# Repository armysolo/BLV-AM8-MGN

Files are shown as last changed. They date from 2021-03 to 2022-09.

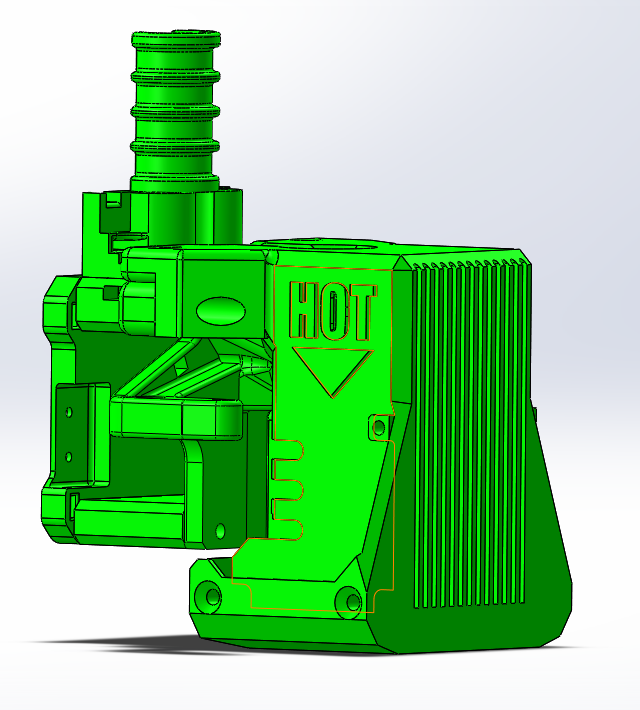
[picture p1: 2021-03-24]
BLV Cube X Carriage for AM8/Pictures/X Carriage Assembly.PNG

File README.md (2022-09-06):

# BLV-AM8-MGN  
# Notice for stepper wiring #  

* Don't trust the data sheet or other schematics to be correct. You should test the wires yourself to find the coil pairs. Do not connect/disconnect the stepper motors while the board has power. You can blow stepper drivers. With the motor wires NOT connected to anything:  
The idea is to find the two cables that form one of the two coils inside the stepper. If you short two wires together and the stepper shaft is hard to turn by hand you found one pair of wires for a coil.  
Example- If black and green wires are a pair call them coil 1, than red and blue can be coil 2.  
* Duet labels the Duet 2 Wifi stepper ports with 2B 2A(red-blue) and 1A 1B(green-black).  
* Duet 3 is labeled B1 B2(black-green) and A1 A2(red-blue).
 
# Rail Relocation Mod #  

* This mod is designed to move the linear rails from the front of the 2040 extrusions to the outside. Having the linear rails on the side makes installing the X 2020 considerably easier. Make sure you line up the linear rails with the 2020 jig from the original download.  

* The original X 2020 was 420mm. This modification will require a 450mm 2020 for the X. You can go longer but the new 2020 needs to be at least 30mm longer. There's 7 parts you'll need to print. View the pictures, the replacement parts are in green. You should be able to reuse the original parts. You'll also need a longer belt.  

# AM8 MGN CoreXY X Carriage #  
* I've modified the X carriage from the CoreXY to work with the AM8 MGN mod. You'll need to print the 7 parts from my mod that moves the linear rails to the outsides of 2040 and all 9 parts for the X carriage. This mod also moves the X endstop from the top of the 2020 to be recessed on the inside of the X Carriage Rear plate. It might not be necessary so you make the choice.  
 
# AM8 MGN CoreXY X Carriage #  
My modified Y belt setup. I didn't start with an original Anet instead I built everything custom from the ground up.  

## BOM ##  
* 2040 Y Motor  
** 2x M5x8mm button head screws  
** 2x M5 T-Nuts  
** 4x M3x8mm socket head screws  

* Y Adjustable Belt Holder  
** 4x M4x12 socket head screws  
** 4x M4 nuts  
** 3x M3 nuts  
** 1x M3x35mm socket head screw  
** 2x M3x6mm button head screws

* Y Tensioner  
** 4x M5x8mm button head screws  
** 4x M5 T-Nuts  
** 1x M3x20mm socket head screw  
** 3x M3 washers
** 2x F6232ZZ bearings

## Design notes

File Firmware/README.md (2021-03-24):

## Firmware
I will only update my configuration files for the latest released versions. I won't do it for the beta versions because they change too frequent. If you find any issues PM me on Facebook. I'm trying to highlight any useful or important information so if I missed something I apologize.  

This firmware will work without modifications needed ONLY if you follow my wiring diagrams. Study and understand the wiring diagrams before you start plugging things in.  

Make sure your M208 in config.g is configured correctly for max and min.  

If upgrading from Duet RRF2 you need to update to RRF3.0.0 before going to the latest released version. After updating to RRF3.0.0 you can go to RRF3.#.#.  

https://duet3d.dozuki.com/Wiki/Installing_and_Updating_Firmware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  

There are a number of changes in RRF3 which makes some of the RRF2 Gcode incompatible.  

https://duet3d.dozuki.com/Wiki/RepRapFirmware_3_overview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  

Become familiar with the firmware. Learn to troubleshoot and use the Duet resources. You'll learn more if figure it out on your own vs always asking someone to fix it for you. Make sure you're using the latest version of the firmware.  

After your build is assembled and firmware configured, DO THE COMMISSION TESTING!!!! I can't stress that enough. It can prevent damage to the printer or the main board.  

https://duet3d.dozuki.com/Wiki/Step_by_step_guide#Section_Commissioning_tests  

Duet Resources/Useful links  
https://duet3d.dozuki.com/Wiki/Getting_Started_With_Duet_3  
https://duet3d.dozuki.com/Wiki/Step_by_step_guide  
https://duet3d.dozuki.com/Wiki/Gcode  
https://duet3d.dozuki.com/Wiki/Bed_levelling_using_multiple_independent_Z_motors  
https://duet3d.dozuki.com/  
https://forum.duet3d.com/  
https://www.blvprojects.com/  

# Independent leveling:  
You must use M671 to define the X and Y coordinates of the leadscrews.  
M671 must come after the M584, M667 or M669.  
Must specify the same quantity of X and Y coordinates as the number of motors assigned to the Z axis in M584  
These coordinates must be in the same order as the driver numbers of the associated motors in M584. 
Define it with the physical location in relation to the nozzle. The S parameter is for the max allowed adjustment.  
G30 defines where the head will probe to calculate the offset.  

**2 Z motors**  
One at each end of the X axis  
Set the Y coordinates of the leadscrews in M671 to be equal (the value doesn't matter, so you can use zero).  
Use at least two probe points, one at each end of the X axis.  
All your probe points should have the same Y coordinate, which should be at or near the middle of the printable range.  

Define the driver in config.g `M584 Z0.3:0.4`  
`M671 X-48.5:360 Y150:150 S10`  
The order the coordinates appear are important. The stepper located at -48.5,150 must be connected to driver 3  
The stepper located at 360,150 must be connected to driver 4  

In bed.g  
`G30 P0 X55 Y161 Z-99999 ; Probe near left lead screw position`  
`G30 P1 X328 Y161 Z-99999 S2 ; Probe near right lead screw position`  

-Note: If you are experiencing the Z axis compensating in the opposite direction needed, that means your Z motors are swapped. 
You can either swap the X values in the M671 command, or swap the stepper motors plugged into the Duet.

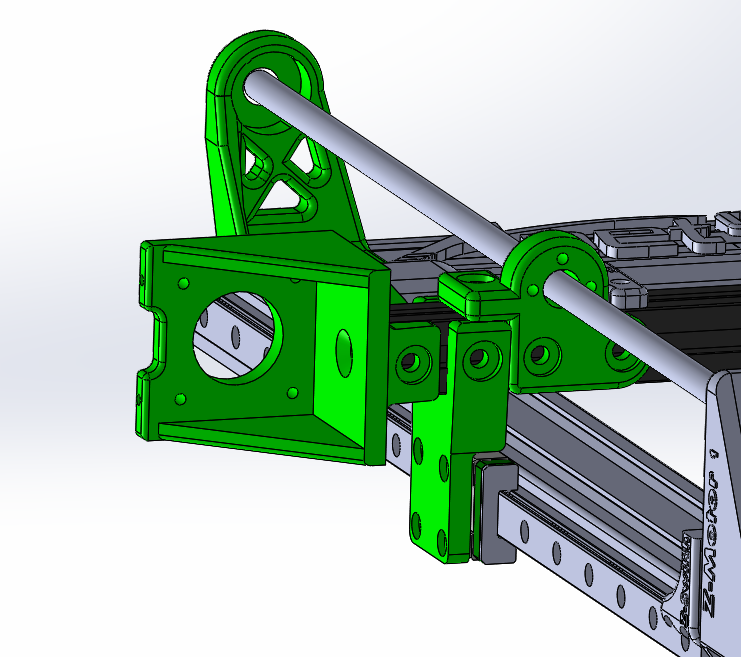
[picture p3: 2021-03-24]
Rail Relocation Mod/Pictures/Left Bottom.PNG

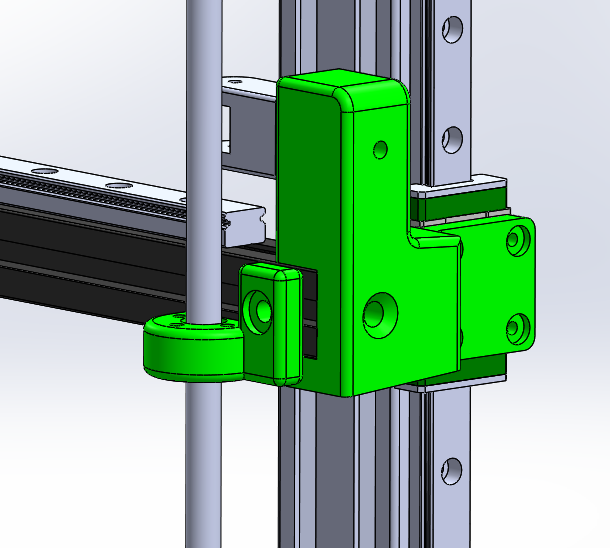
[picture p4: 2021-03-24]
Rail Relocation Mod/Pictures/Right X.PNG

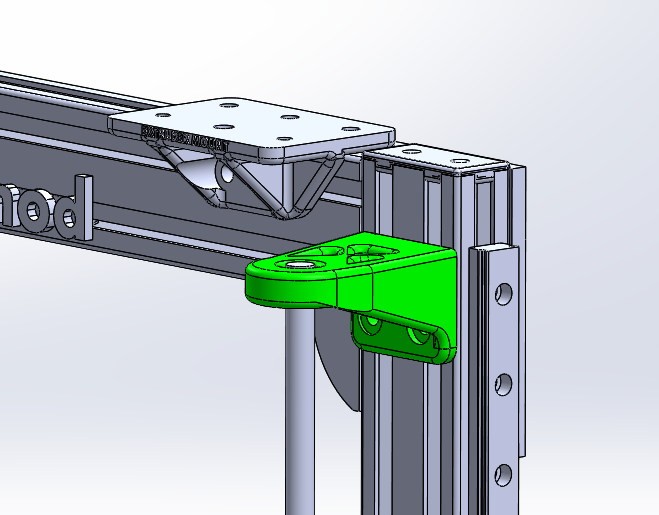
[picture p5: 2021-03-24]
Rail Relocation Mod/Pictures/Right Top.PNG

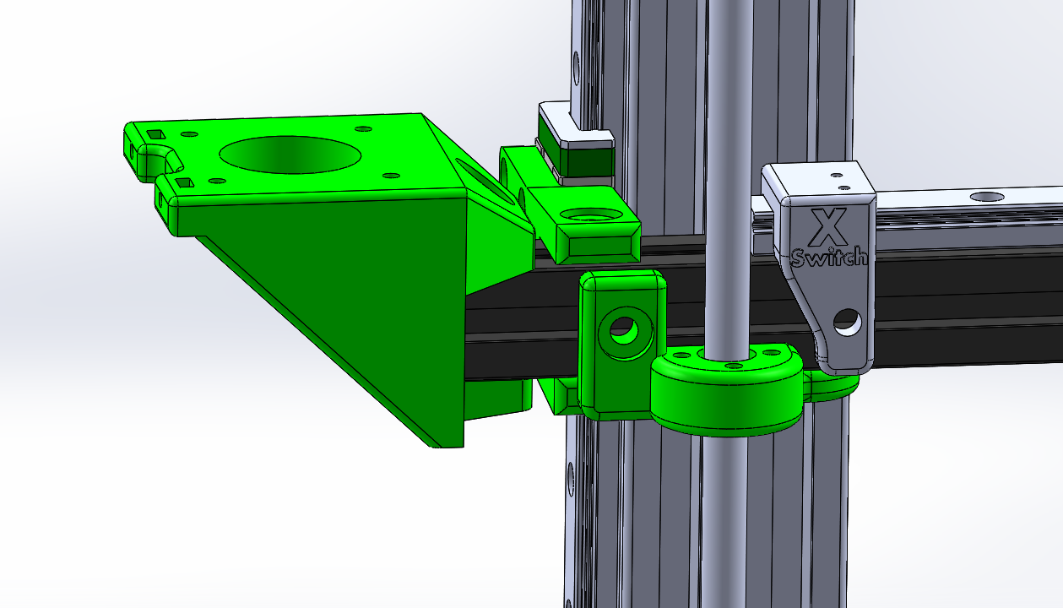
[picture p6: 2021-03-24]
Rail Relocation Mod/Pictures/Left X.PNG

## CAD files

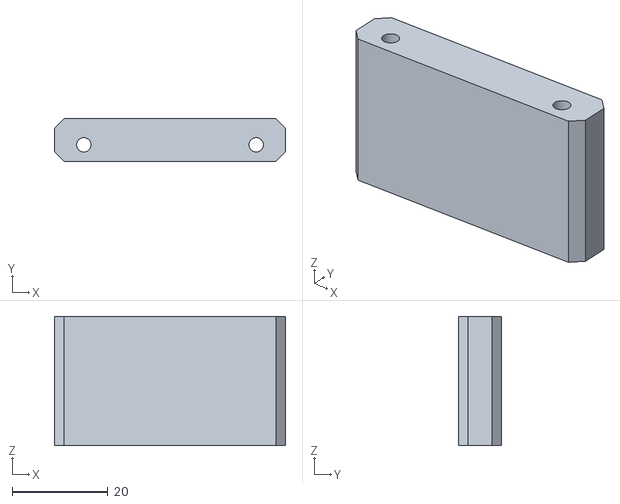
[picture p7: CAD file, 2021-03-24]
BLV Cube X Carriage for AM8/STL/X Carriage - Bottom.STL
48.2 x 9.00 x 27.0

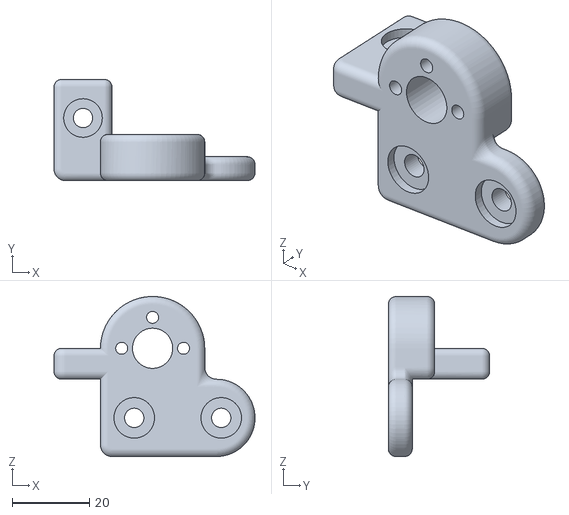
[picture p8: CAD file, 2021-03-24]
Rail Relocation Mod/STL/BLV AM8 MGN Left Z Mount.STL
52.0 x 26.2 x 41.4

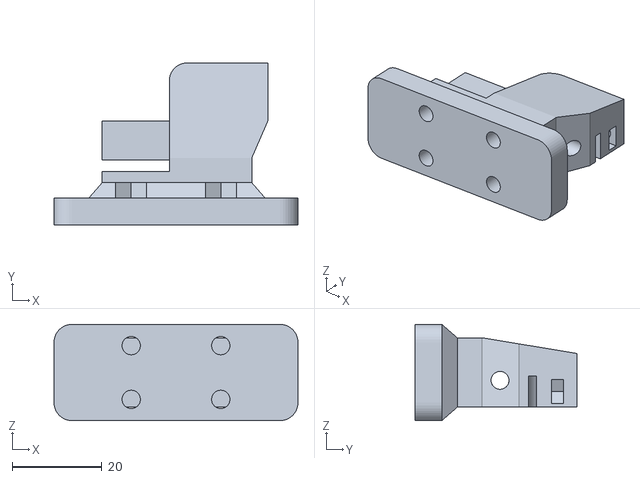
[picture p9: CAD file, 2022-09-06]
Y Belt Tensioner Alternative/Y Adjustable Belt Holter.STL
54.5 x 36.2 x 21.5

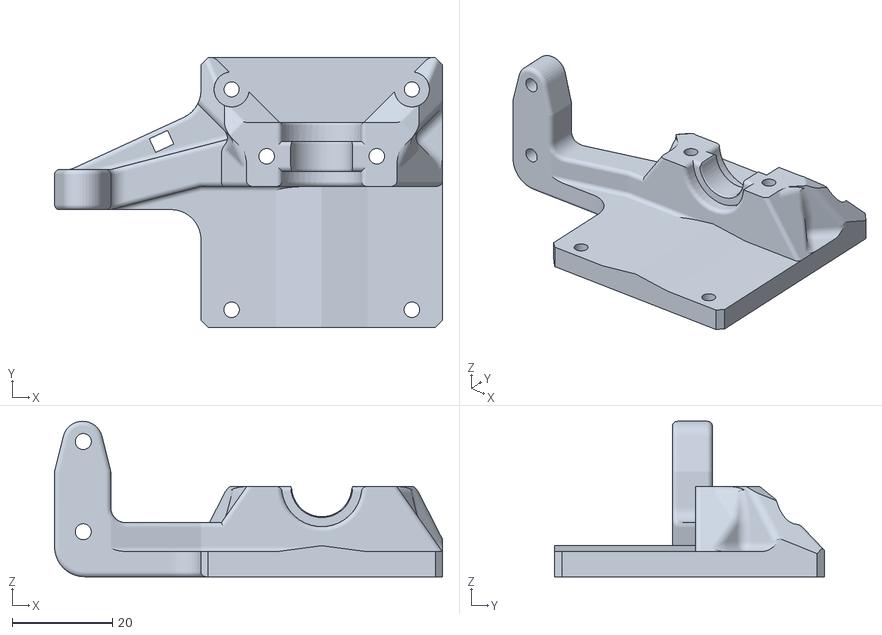
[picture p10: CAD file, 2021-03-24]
BLV Cube X Carriage for AM8/STL/X Carriage - Front Plate.STL
77.5 x 53.8 x 31.1

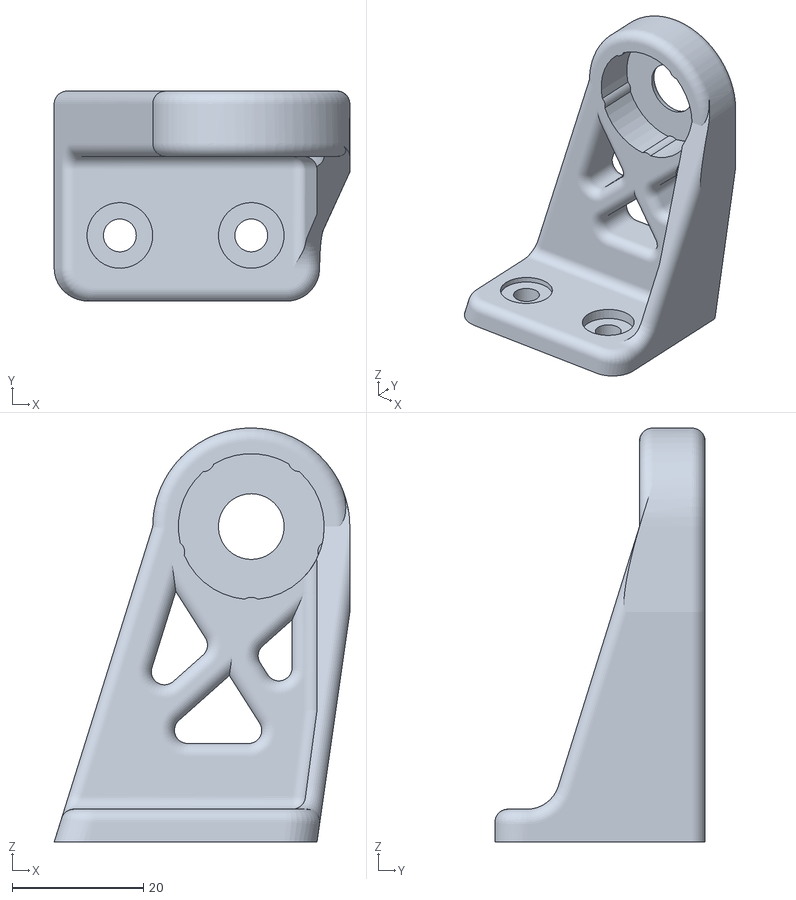
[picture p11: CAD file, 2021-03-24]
Rail Relocation Mod/STL/BLV AM8 MGN RT Top Holder.STL
45.0 x 32.0 x 63.0

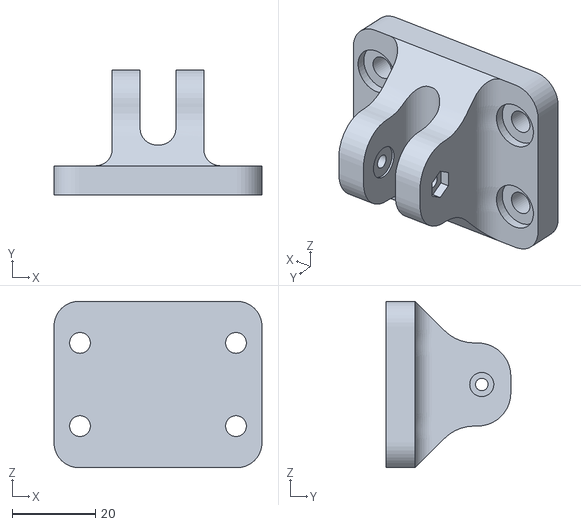
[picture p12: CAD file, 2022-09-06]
Y Belt Tensioner Alternative/3mm Y tensioner.STL
50.0 x 30.0 x 40.0

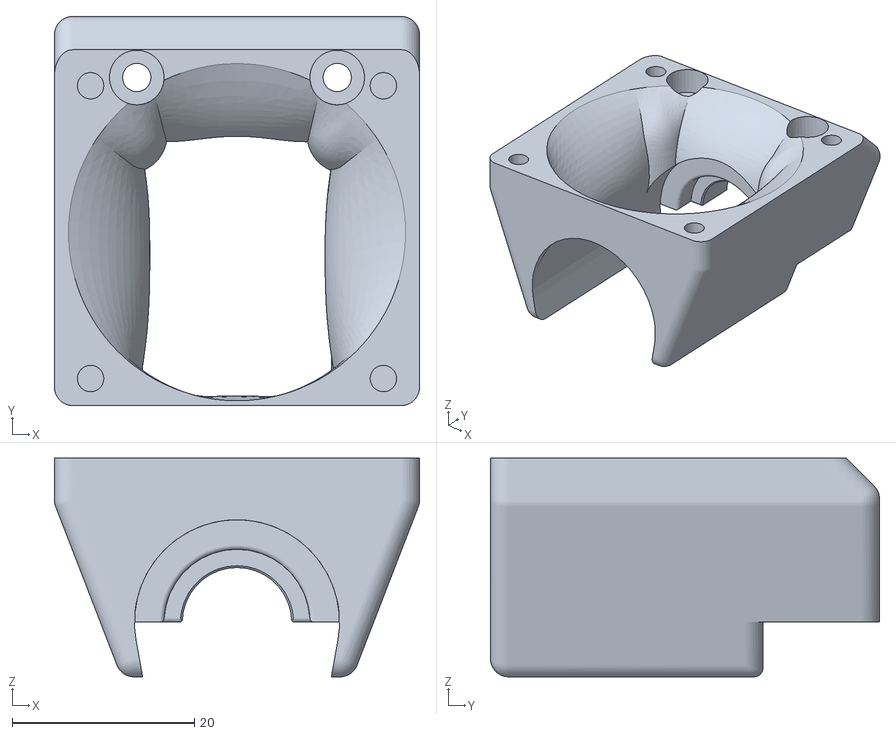
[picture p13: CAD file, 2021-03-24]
BLV Cube X Carriage for AM8/STL/X Carriage - E3D V6 Locker.STL
40.1 x 42.7 x 24.0

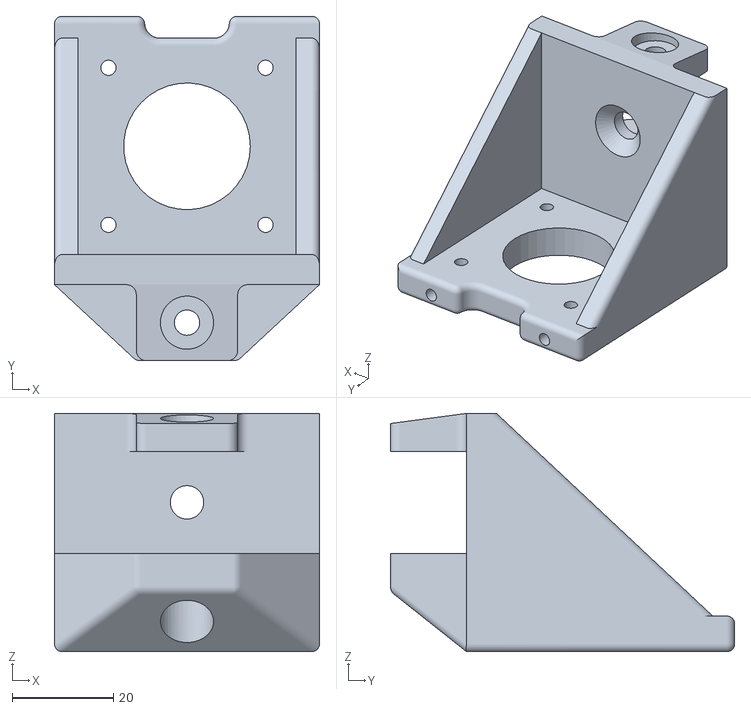
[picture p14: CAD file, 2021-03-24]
Rail Relocation Mod/STL/BLV AM8 MGN X Motor Mount.STL
52.3 x 67.9 x 47.0

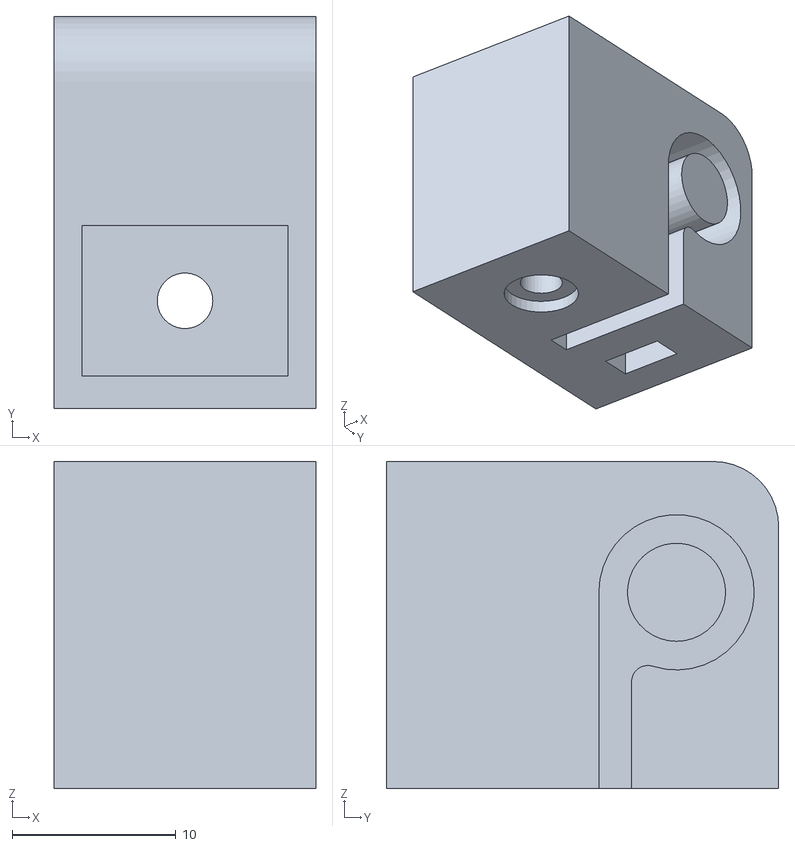
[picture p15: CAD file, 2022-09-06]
Y Belt Tensioner Alternative/Y Belt slide.STL
16.0 x 24.0 x 20.0

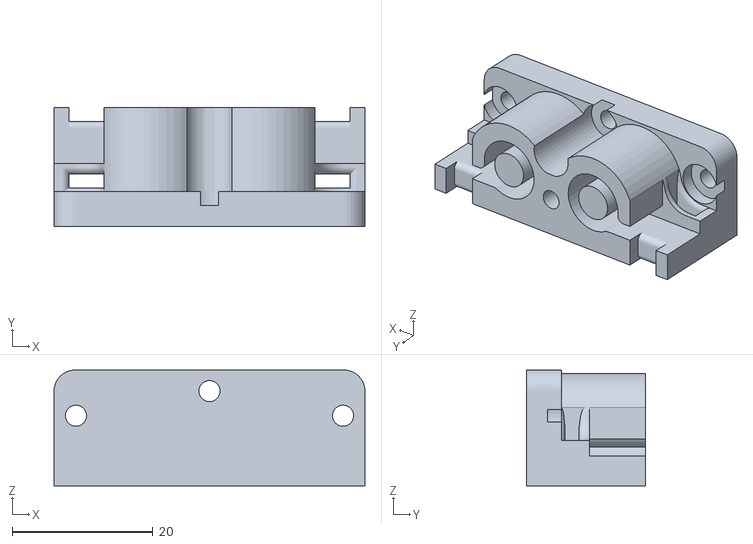
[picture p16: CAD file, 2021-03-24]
BLV Cube X Carriage for AM8/STL/X Carriage - Top Belt Mount.STL
44.2 x 17.0 x 16.5

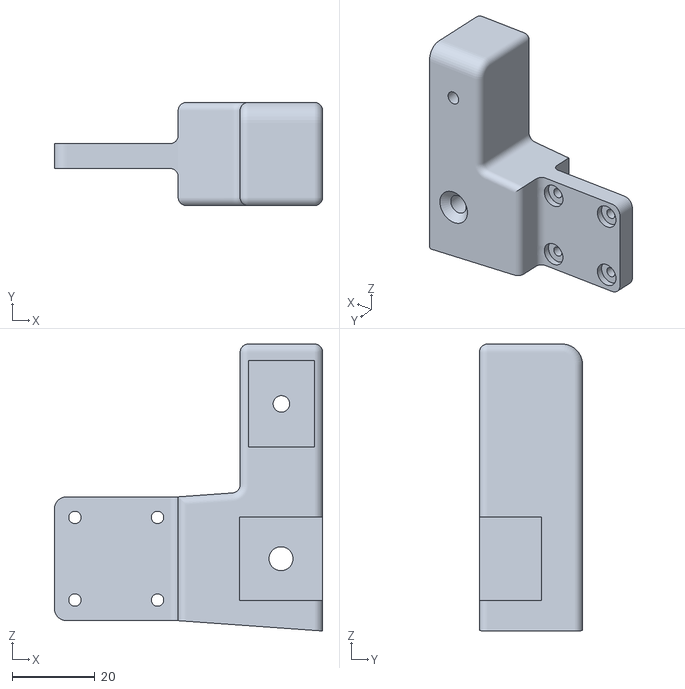
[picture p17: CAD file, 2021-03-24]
Rail Relocation Mod/STL/BLV AM8 MGN Z Right Mount.STL
65.0 x 25.0 x 69.5

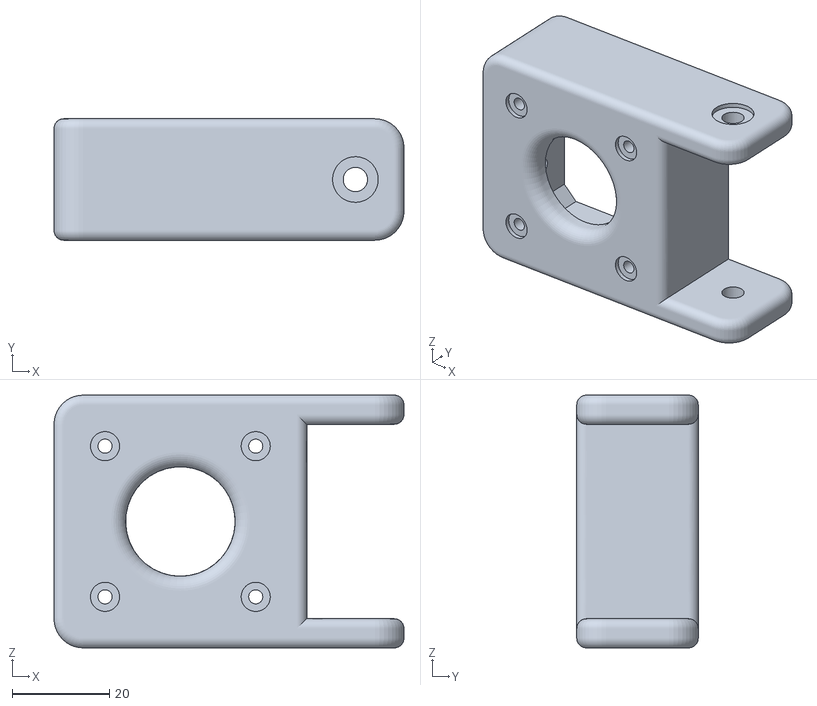
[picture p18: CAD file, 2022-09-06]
Y Belt Tensioner Alternative/2040 Y Motor2.STL
72.0 x 25.0 x 52.0

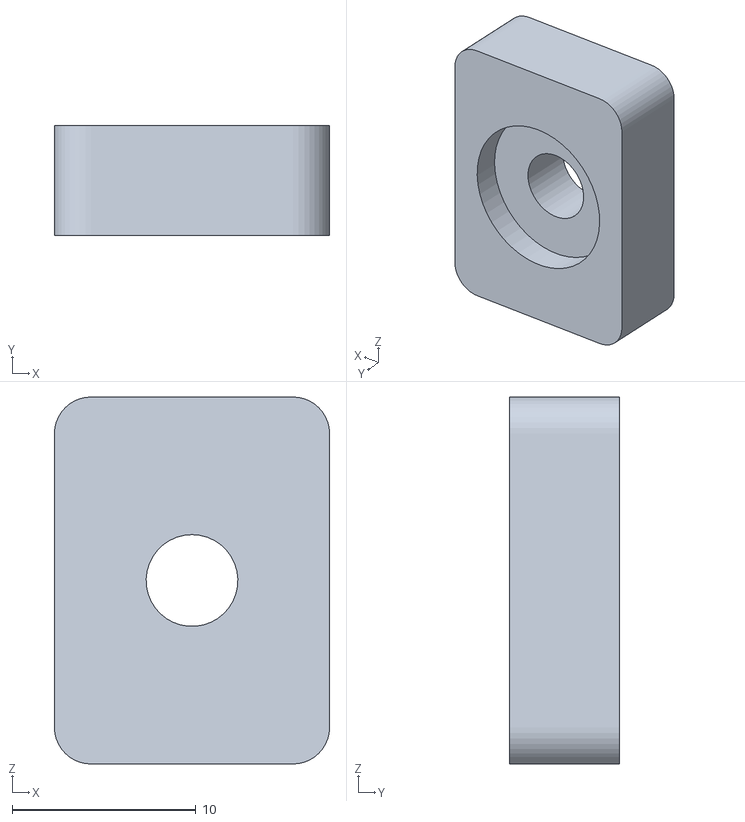
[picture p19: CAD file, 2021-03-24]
BLV Cube X Carriage for AM8/STL/X Carriage - X Endstop Stopper.STL
15.0 x 6.00 x 20.0

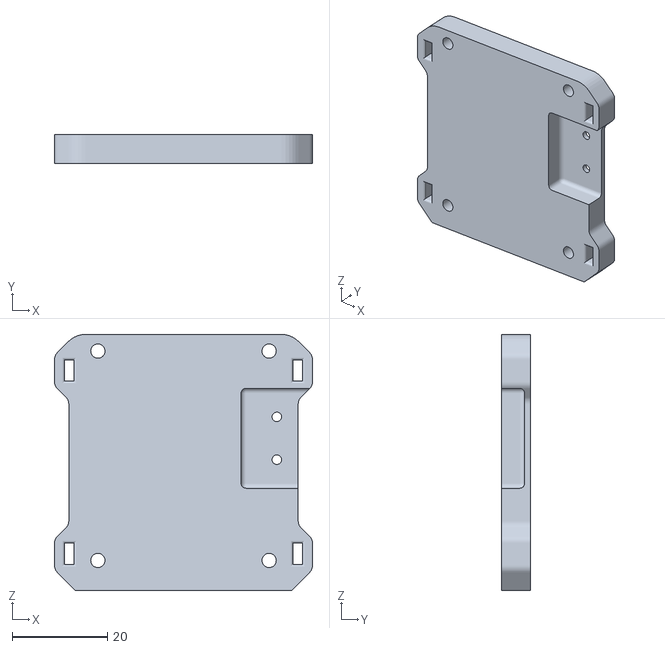
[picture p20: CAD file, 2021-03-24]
BLV Cube X Carriage for AM8/STL/X Carriage - Rear Plate.STL
54.2 x 6.00 x 53.8

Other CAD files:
Rail Relocation Mod/STL/BLV AM8 MGN LT Top Holder.STL
Rail Relocation Mod/STL/BLV AM8 MGN Z Left Mount.STL
BLV Cube X Carriage for AM8/STL/X Carriage - Top Cable Locker.STL
Rail Relocation Mod/STL/BLV AM8 MGN Right Z Mount.STL
BLV Cube X Carriage for AM8/STL/X Carriage - Block Shield Twin Blower.STL
BLV Cube X Carriage for AM8/STL/X Carriage - MGN Block.STL

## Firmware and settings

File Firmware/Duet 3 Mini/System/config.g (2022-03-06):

; Configuration file for Duet 3 Mini (firmware version 3)
; executed by the firmware on start-up
;
; Created by David Husolo November 15 2021

; General preferences
G90															; send absolute coordinates...
M83															; ...but relative extruder moves
M669 K0														; Select Cartesian mode

; Drives
M569 P0.0 S0												; physical drive 0 goes forwards
M569 P0.1 S1												; physical drive 1 goes backwards
M569 P0.2 S0												; physical drive 2 goes forwards
M569 P0.3 S1												; physical drive 3 goes backwards
M569 P0.4 S1												; physical drive 3 goes forwards
M584 X0.1 Y0.2 Z0.3:0.4 E0.0								; set drive mapping
M350 X32 Y32 I0												; configure microstepping without interpolation
M350 Z16 E16 I1												; configure microstepping with interpolation
M92 X160.00 Y160.00 Z400.00 E415.15							; set steps per mm
M566 X800.00 Y800.00 Z240.00 E2000.00						; set maximum instantaneous speed changes (mm/min)
M203 X18000.00 Y18000.00 Z1000.00 E12000.00					; set maximum speeds (mm/min)
M201 X1500.00 Y1500.00 Z120.00 E4000.00						; set accelerations (mm/s^2)
M906 X1600 Y1600 Z1500 E1600 I30							; set motor currents (mA) and motor idle factor in per cent
M84 S120													; Set idle timeout

; Axis Limits
M208 X-8 Y-18 Z0 S1											; set axis minima
M208 X297 Y280 Z216 S0										; set axis maxima

; Endstops
M574 X1 S1 P"0.io2.in"										; configure active-high endstop for low end on X via pin xstop
M574 Y1 S1 P"0.io3.in"										; configure active-high endstop for low end on Y via pin ystop
M574 Z1 S2													; configure Z-probe endstop for low end on Z
M591 D0 P1 C"0.io5.in" S1									; configure filament runout sensor for high end on extruder drive 0 via pin i03.in

; Z-Probe
M950 S0 C"0.io1.out"										; create servo pin 0 for BLTouch
M558 P9 C"^0.io1.in" H5 F200 T9000							; set Z probe type to bltouch and the dive height + speeds
G31 P100 X0 Y0 Z2.023										; set Z probe trigger value, offset and trigger height

; Heaters
M308 S0 P"0.temp0" Y"thermistor" A"Bed" T100000 B3950 C0.06e-8 ; configure sensor 0 as thermistor on pin bedtemp
M950 H0 C"0.out0" T0										; create bed heater output on bedheat and map it to sensor 0
M307 H0 B0 R0.301 C811.5 D31.63 S1.00						; Heatbed PID
M140 H0														; map heated bed to heater 0
M143 H0 S120												; set temperature limit for heater 0 to 120C
M308 S1 P"0.temp1" Y"thermistor" A"Hotend" T100000 B3950 C0.06e-8  ; configure sensor 1 as thermistor on pin e0temp
M950 H1 C"0.out1" T1										; create nozzle heater output on e0heat and map it to sensor 1
M307 H1 B0 R2.378 C138.1 D8.08 S1.00 V23.9					; Hotend PID .4mm
M143 H1 S260
M308 S2 P"mcu-temp" Y"mcu-temp" A"Duet Board"				; Configure MCU sensor

; Fans
M950 F0 C"0.out3" Q500										; create fan 0 on pin fan0 and set its frequency
M106 P0 C"LY Fan1" S0 H-1									; set fan 0 value. Thermostatic control is turned on
M950 F1 C"0.out4" Q500										; create fan 0 on pin fan0 and set its frequency
M106 P1 C"LY Fan2" S0 H-1									; set fan 0 value. Thermostatic control is turned on
M950 F2 C"0.out5" Q500										; create fan 0 on pin fan0 and set its frequency
M106 P2 C"HE Fan" S1 H1 T40									; set fan 0 value. Thermostatic control is turned on
M950 F3 C"0.out6" Q500										; create fan 1 on pin fan1 and set its frequency
M106 P3 C"MB Fan" T40 H2									; set fan 0 value. Thermostatic control is turned on

; Tools
M563 P0 D0 H1 F0:1											; define tool 0
G10 P0 X0 Y0 Z0												; set tool 0 axis offsets
G10 P0 R0 S0												; set initial tool 0 active and standby temperatures to 0C

; Custom settings
M564 H0														; Let the Jog buttons work blv: added to allow jog buttons

; Shutdown button
M950 J1 C"!0.io6.in"										; Create GPIO pin for On button wired NO-must be inverted with !
M581 T2 P1 S1 R0											; T2-Run Trigger 2; P1-J1; S1-When button pressed; R0-trigger any time

; Miscellaneous
M575 P1 S1 B57600											; enable support for PanelDue
;M918 P2 E4 R6 ; configure direct-connect display

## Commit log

2021-03-24 File Upload
    [BLV AM8 MGN LT Top Holder.STL, BLV AM8 MGN Left Z Mount.STL, BLV AM8 MGN RT Top Holder.STL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]
2022-03-06 Update firmware files
    [bed.g, cancel.g, config.g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]
2022-09-06 Y Belt Tensioner Alternative
    [2040 Y Motor2.STL, 3mm Y tensioner.STL, Y Adjustable Belt Holter.STL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]
2022-09-06 Update Y Adjustable Belt Holter.STL
    [Y Adjustable Belt Holter.STL]
